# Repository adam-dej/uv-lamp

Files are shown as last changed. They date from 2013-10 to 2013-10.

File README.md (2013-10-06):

uv-lamp
=======

Easy-to-construct UV lamp for exposition of PCB's with programmable timer, licensed under TAPR Open Hardware License.

This lamp is using 15 UV LEDs for PCB exposition. It can handle exposing 150x110 sized PCB's.

Schematic was created with KiCad.

Complete documentation and user manual is here: http://frozendevs.com/wiki/doku.php?id=wiki:uv-lamp

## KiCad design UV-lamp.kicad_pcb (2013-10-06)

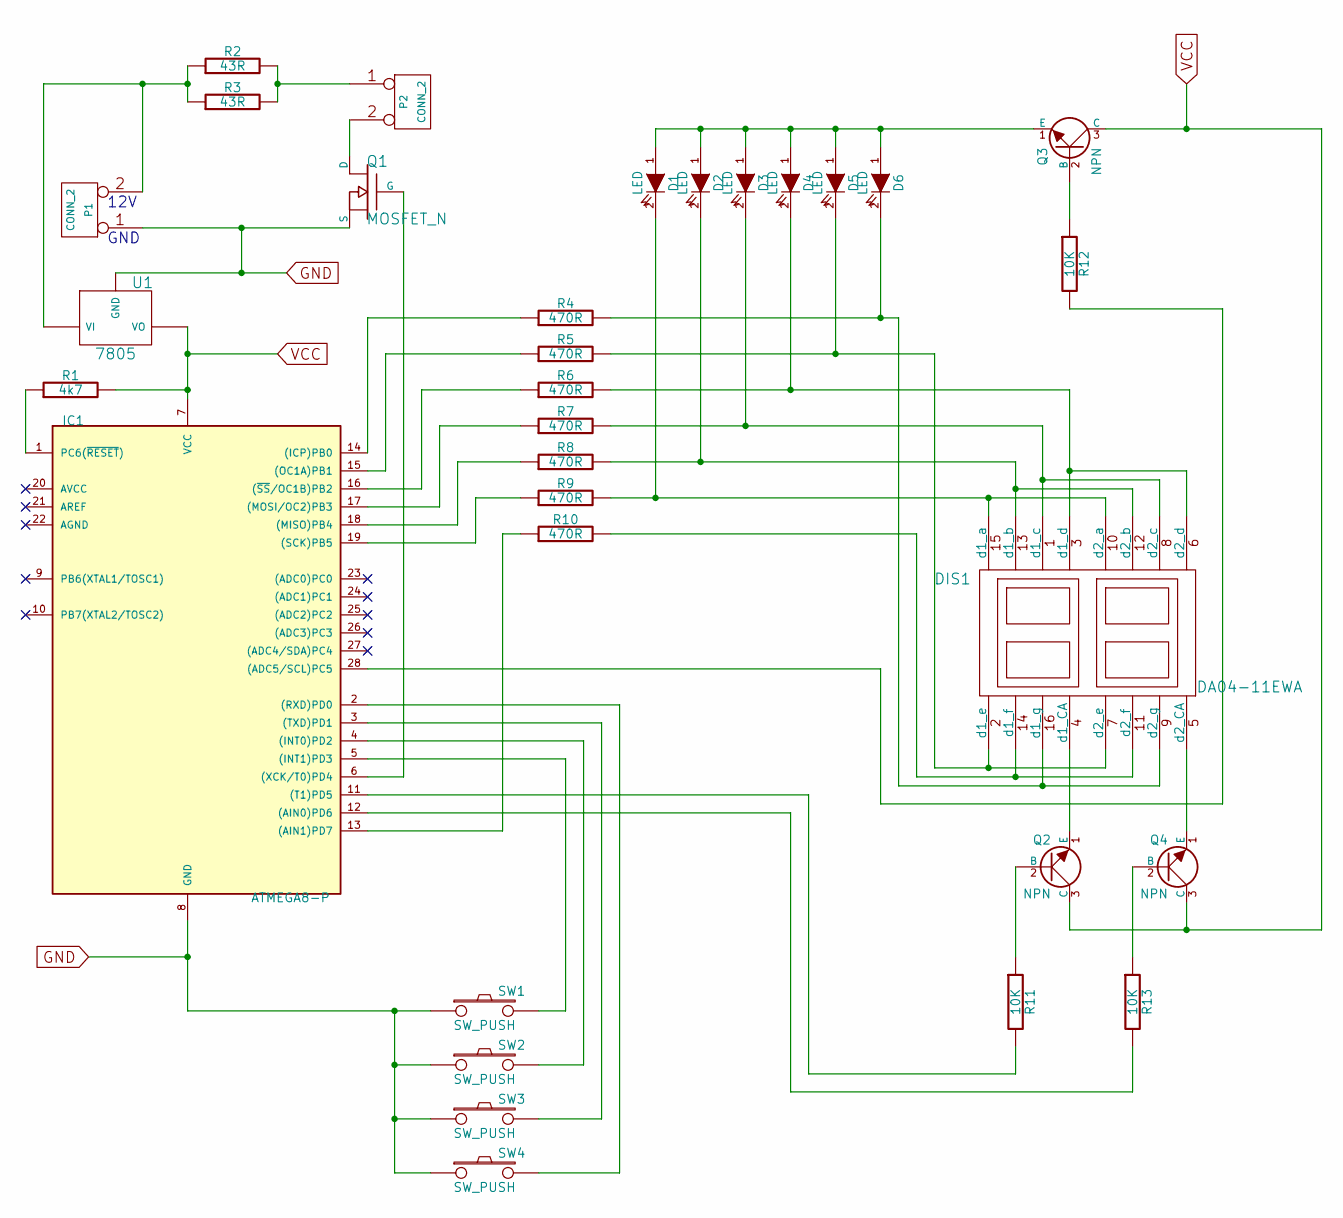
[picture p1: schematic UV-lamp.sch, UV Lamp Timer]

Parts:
D1, D2, D3, D4, D5, D6: LED
DIS1: DA04-11EWA
IC1: ATMEGA8-P; DIL28
P1, P2: CONN_2
Q1: MOSFET_N
Q2, Q3, Q4: NPN
R1: 4k7
R2, R3: 43R
R4, R5, R6, R7, R8, R9, R10: 470R
R11, R12, R13: 10K
SW1, SW2, SW3, SW4: SW_PUSH
U1: 7805

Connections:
GND: IC1.8 (GND), P1.1, Q1.S, SW1.1, SW2.1, SW3.1, SW4.1, U1.GND
unnamed: D1.1 (A), D2.1 (A), D3.1 (A), D4.1 (A), D5.1 (A), D6.1 (A), Q3.1 (E)
unnamed: IC1.28 ((ADC5/SCL)PC5), R12.2
unnamed: Q3.2 (B), R12.1
unnamed: IC1.19 ((SCK)PB5), R9.1
unnamed: IC1.13 ((AIN1)PD7), R10.1
unnamed: IC1.18 ((MISO)PB4), R8.1
unnamed: IC1.17 ((MOSI/OC2)PB3), R7.1
unnamed: IC1.5 ((INT1)PD3), SW1.2
unnamed: IC1.2 ((RXD)PD0), SW4.2
unnamed: P2.2 (PM), Q1.D
unnamed: IC1.3 ((TXD)PD1), SW3.2
unnamed: IC1.4 ((INT0)PD2), SW2.2
unnamed: DIS1.4 (d1_CA), Q2.1 (E)
unnamed: IC1.12 ((AIN0)PD6), R13.2
unnamed: DIS1.5 (d2_CA), Q4.1 (E)
unnamed: Q2.2 (B), R11.1
unnamed: Q4.2 (B), R13.1
unnamed: IC1.11 ((T1)PD5), R11.2
unnamed: D4.2 (K), DIS1.3 (d1_d), DIS1.6 (d2_d), R6.2
unnamed: IC1.1 (PC6(~RESET~)), R1.1
unnamed: P1.2 (PM), R2.1, R3.1, U1.VI
unnamed: D2.2 (K), DIS1.12 (d2_b), DIS1.13 (d1_b), R8.2
unnamed: IC1.15 ((OC1A)PB1), R5.1
unnamed: IC1.14 ((ICP)PB0), R4.1
unnamed: DIS1.11 (d2_f), DIS1.14 (d1_f), R10.2
unnamed: D1.2 (K), DIS1.10 (d2_a), DIS1.15 (d1_a), R9.2
unnamed: D6.2 (K), DIS1.9 (d2_g), DIS1.16 (d1_g), R4.2
unnamed: D3.2 (K), DIS1.1 (d1_c), DIS1.8 (d2_c), R7.2
unnamed: D5.2 (K), DIS1.2 (d1_e), DIS1.7 (d2_e), R5.2
unnamed: IC1.6 ((XCK/T0)PD4), Q1.G
unnamed: IC1.16 ((~SS~/OC1B)PB2), R6.1
unnamed: P2.1, R2.2, R3.2
VCC: IC1.7 (VCC), Q2.3 (C), Q3.3 (C), Q4.3 (C), R1.2, U1.VO

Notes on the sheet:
GND
12V

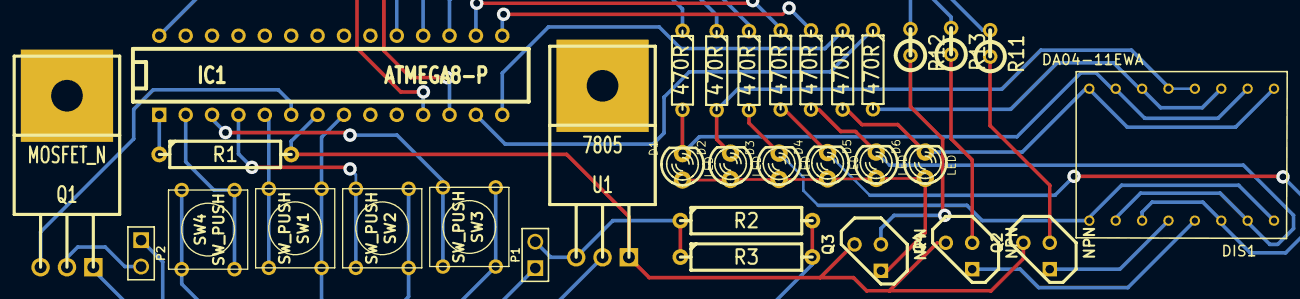
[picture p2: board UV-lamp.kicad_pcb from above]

Board: 2 copper layers, 32 parts (0 on the bottom side), 34 nets.

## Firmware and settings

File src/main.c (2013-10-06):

/*
 * main.c
 *
 *  Created on: Apr 7, 2013
 *      Author: deykoweec
 */


#include <avr/io.h>
#include <avr/interrupt.h>
#include <util/delay.h>

#define sbi(PORT, PIN) PORT |= (1 << PIN)
#define cbi(PORT, PIN) PORT &= ~(1 << PIN)

#define ON 1
#define OFF 0

void init_io();
void _blank_display();
void init_timers();
void main_timer_start();
void main_timer_stop();
void blink_timer_start();
void blink_timer_stop();
void enable_INT0();
void disable_INT0();
void enable_INT1();
void disable_INT1();
void lamp(int state);
void init_ext_interrupts();

uint8_t digit = 0;
uint8_t minute = 0;
uint8_t blink = 0;
uint8_t digit_edit = 0;
uint8_t lamp_state = 0;

int number = 0;

ISR(INT0_vect) {
	if (digit_edit == 0) digit_edit = 1;
	else digit_edit = 0;
	disable_INT0();
}

ISR(INT1_vect) {
	disable_INT1();
	if (minute == 0 && number == 0 && lamp_state == 1) {
		lamp(OFF);
		lamp_state = 0;
	} else if (minute == 0 && number == 0 && lamp_state == 0) {
		lamp(ON);
		lamp_state = 1;
	} else {
		if (lamp_state == 0) {
			lamp(ON);
			lamp_state = 1;
			main_timer_start();
			blink_timer_stop();
		} else {
			lamp(OFF);
			lamp_state = 0;
			main_timer_stop();
			blink_timer_start();
		}
	}
}

ISR(TIMER1_COMPB_vect) {
	if (number > 0) number--;
	else {
		if (minute > 0) {
			number = 59;
			minute--;
		} else {
			main_timer_stop();
		}
	}
	if (number == 0 && minute == 0) {
		lamp(OFF);
		lamp_state = 0;
		blink_timer_start();
	}
	TCNT1 = 0;
}

ISR(TIMER2_OVF_vect) {
	if (blink < 10) blink++;
	else blink = 0;
}

ISR(TIMER0_OVF_vect) {

	uint8_t d = 0;
	_blank_display();

	switch(digit) {
	case 0:
		cbi(PORTC, 5);
		if (!(digit_edit == 0 && blink < 1)) sbi(PORTD, 5);
		d = number/10;
		break;
	case 1:
		cbi(PORTD, 5);
		sbi(PORTD, 6);
		d = number%10;
		break;
	case 2:
		cbi(PORTD, 6);
		if (!(digit_edit == 1 && blink < 1)) sbi(PORTC, 5);
		PORTB = ~(minute << 1);
		break;
	}

	if (digit < 2) {
		digit++;
		if (d != 4 && d != 1) cbi(PORTB, 5);
		if (d != 5 && d != 6) cbi(PORTB, 4);
		if (d != 2) cbi(PORTB, 3);
		if (d != 1 && d != 4 && d != 7) cbi(PORTB, 2);
		if (d == 2 || d == 6 || d == 0 || d == 8) cbi(PORTB, 1);
		if ((d > 3 && d != 7) || d == 0) cbi(PORTD, 7);
		if (d != 1 && d != 7 && d != 0) cbi(PORTB, 0);
	}
	else digit = 0;



}


int main(void) {

	init_io();
	init_ext_interrupts();
	init_timers();

	minute = 0;
	number = 0;

	lamp(OFF);
	enable_INT0();
	enable_INT1();

	blink_timer_start();

	while(1) {
		if (!bit_is_set(PIND, 0) && ((digit_edit == 0 && number < 60) | (digit_edit == 1 && minute < 31)) && !bit_is_set(TCCR1B, CS12)) {
			if (digit_edit == 0) number += 10;
			else minute++;
			_delay_ms(200);
			while(!bit_is_set(PIND, 0)) {
				_delay_ms(100);
				if (!bit_is_set(PIND, 0) && ((digit_edit == 0 && number < 60) | (digit_edit == 1 && minute < 31))) {
					if (digit_edit == 0) number += 10;
					else minute++;
				}
			}
		}
		if (!bit_is_set(PIND, 1) && ((digit_edit == 0 && number >= 10) | (digit_edit == 1 && minute > 0)) && !bit_is_set(TCCR1B, CS12)) {
			if (digit_edit == 0) number -= 10;
			else minute--;
			_delay_ms(200);
			while (!bit_is_set(PIND, 1)) {
				_delay_ms(100);
				if (!bit_is_set(PIND, 1) && ((digit_edit == 0 && number >= 10) | (digit_edit == 1 && minute > 0))) {
					if (digit_edit == 0) number -= 10;
					else minute--;
				}
			}
		}
		if (!bit_is_set(GICR, INT0)) {
			_delay_ms(500);
			GIFR |= (1 << INTF0);
			enable_INT0();
		}
		if (!bit_is_set(GICR, INT1)) {
			_delay_ms(500);
			GIFR |= (1 << INTF1);
			enable_INT1();
		}
	}

	while(1);


}

void init_io() {
	sbi(DDRB, 5);
	sbi(DDRB, 4);
	sbi(DDRB, 3);
	sbi(DDRB, 2);
	sbi(DDRB, 1);
	sbi(DDRB, 0);
	sbi(DDRD, 7);
	sbi(DDRD, 6);
	sbi(DDRD, 5);

	sbi(DDRD, 4);

	cbi(DDRD, 0);
	cbi(DDRD, 1);
	sbi(PORTD, 0);
	sbi(PORTD, 1);
}

void _blank_display() {
	sbi(PORTB, 5);
	sbi(PORTB, 4);
	sbi(PORTB, 3);
	sbi(PORTB, 2);
	sbi(PORTB, 1);
	sbi(PORTB, 0);
	sbi(PORTD, 7);
}

void init_timers() {
	TIMSK |= (1 << TOIE0);
	TIMSK |= (1 << TOIE2);
	TIMSK |= (1 << OCIE1B);
	TCNT0 = 0;
	OCR1B = 31250; //Compare every second with 8MHz and /256 prescaler
	sei();
	TCCR0 |= (1 << CS01) | (1 << CS00);
}

void blink_timer_start() {
	TCCR2 |= (1 << CS22) | (1 << CS21) | (1 << CS20);
}

void blink_timer_stop() {
	TCCR2 &= ~((1 << CS22) | (1 << CS21) | (1 << CS20));
	blink = 5;
}

void main_timer_start() {
	TCCR1B |= (1 << CS12);
}

void main_timer_stop() {
	TCCR1B &= ~(1 << CS12);
}

void init_ext_interrupts() {
	cbi(DDRD, 2);
	cbi(DDRD, 3);
	sbi(PORTD, 2);
	sbi(PORTD, 3);
	MCUCR |= (1 << ISC11) | (1 << ISC01);
}

void enable_INT0() {
	GICR |= (1 << INT0);
}

void disable_INT0() {
	GICR &= ~(1 << INT0);
}

void enable_INT1() {
	GICR |= (1 << INT1);
}

void disable_INT1() {
	GICR &= ~(1 << INT1);
}

void lamp(int state) {
	if (state) sbi(PORTD, 4);
	else cbi(PORTD, 4);
}

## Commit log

2013-10-06 Commit revision B
    [UV-lamp.kicad_pcb, UV-lamp.sch]
2013-10-06 Add license notice to the schematic and PCB layout
    [UV-lamp.kicad_pcb, UV-lamp.sch]
